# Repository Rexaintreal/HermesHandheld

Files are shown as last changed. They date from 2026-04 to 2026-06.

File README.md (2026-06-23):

# HermesHandheld

A portable handheld retro gaming console built from scratch using a Raspberry Pi Zero 2W with a 5" display, physical controls, battery management, and audio output. Designed to run NDS and other retro emulators.

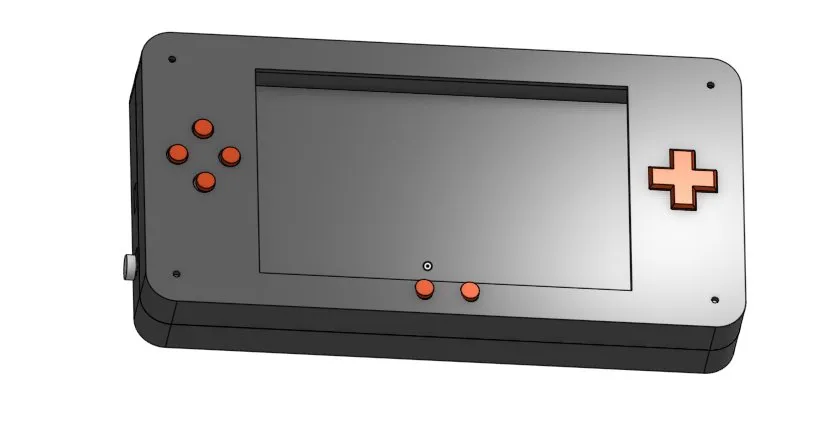
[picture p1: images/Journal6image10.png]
Assembly


> [!NOTE]
> **Currently on a short break!** I'm busy at the moment but will be actively continuing development soon. Stay tuned for updates!

---

## What is it?

Hermes is a fully custom handheld gaming console 3D printed case, hand-wired controls, and a Pi Zero 2W running emulators. Everything from the schematic to the CAD was designed from scratch.

---

## Why I built this

So while looking for inpirations for a Forge project i stubmled across the [simplyRetroZ5](https://www.printables.com/model/163507-simplyretro-z5-retropie-emulation-handheld) repository and i was really amazed by this project and i decided to build smthing like this myself but it would be challenging as ive never made anything from scratch before (in hardware). I had never made a schematic, never done CAD and had no experience with hardware design. But i wanted a project which would help me actually learn all of that not just follow some tutorial online. So instead of cloning it i found parts myself, created the case wiring schematic all myself from scratch. Currently Hermes is under development and im actively working on it whenever im free! 

## Features

- Raspberry Pi Zero 2W (64-bit, capable of NDS emulation)
- Waveshare 5" HDMI display
- ABXY buttons + D-Pad + Start/Select
- LiPo battery (3000mAh) with Adafruit PowerBoost 1000C for stable 5V + charging
- 3.5mm wired audio jack
- Slide switch power on/off
- Fully 3D printed enclosure (195×100×15mm)
- MicroUSB charging port

---

## Repo Structure

```
HermesHandheld/
├── ASSEMBLY.md         # Assembly guide 
├── JOURNAL.md          # Build log with progress photos
├── bom/bom.md          # Full bill of materials
├── cad/                # STL files for 3D printing
├── schematics/         # KiCad schematic + PDF export
└── images/             # All journal and build images
```

---

## CAD

All parts designed in OnShape from scratch.

[View OnShape Assembly](https://cad.onshape.com/documents/3f5750065cdf21957d49744e/w/c6da2cc7c075b2bb5bd5add7/e/7ea9707faccdc6ff577339ba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)

Printable STLs are in the `/cad` folder:
- `top_shell_ds.stl`
- `bottom_shell_ds.stl`
- `abxy_button.stl` (print x6)
- `dpad.stl`
- `power_button.stl`

---

## Schematic

Designed in KiCad. Uses Pi Zero 2W internal pull-ups for buttons (no external resistors needed).



[View Full Schematic PDF](schematics/HermesHandheld.pdf)
---

## Bill of Materials

[View BOM](bom/bom.md)

| Part | Details |
|---|---|
| Raspberry Pi Zero 2W | Main compute |
| Waveshare 5 Display | 121×76mm HDMI |
| Adafruit PowerBoost 1000C | LiPo charging + 5V boost |
| LiPo Battery 3000mAh | 3.7V, 60×50mm |
| Tactile buttons (x10) | 6×6×5mm |
| 3.5mm audio jack | Wired audio via GPIO18 |
| Slide switch | Power on/off |

---

## Build Journal

Full build log with progress photos: [JOURNAL.md](JOURNAL.md)

---

## Status

> CAD complete, schematic done, need to buy parts

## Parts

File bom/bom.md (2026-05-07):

# Bill of Materials 

| Item | Description | Quantity | Unit Price ($) | Total Price ($) | URL |
|---|---|---|---|---|-----|
| Raspberry Pi Zero 2 W | Main compute board (quad-core ARM CPU) | 1 | 20 | 20 | https://robu.in/product/raspberry-pi-zero-2-w/ |
| MicroSD Card 32GB (A1/A2) | OS + emulator + ROM storage | 1 | 6 | 6 | https://sharvielectronics.com/product/sandisk-32gb-class-10-ultra-microsd-uhs-u1a1-card-98mbps/ |
| 5" HDMI IPS Display (800×480) | Non-touch HDMI display for handheld | 1 | 30 | 30 | https://robu.in/product/waveshare-5inch-display-for-raspberry-pi-800x480-dpi-interface-ips-no-touch/ |
| HDMI To Mini HDMI Cable | HDMI connection for Pi/display setup | 1 | 2 | 2 | https://sharvielectronics.com/product/hdmi-to-mini-hdmi-cable-1-5-meter/ |
| LiPo Battery 3.7V 3000mAh | Main power source | 1 | 4.5 | 4.5 | https://www.electronicscomp.com/3.7v-3000mah-lipo-battery-india |
| Adafruit PowerBoost 1000C | Battery charging + 5V boost regulator | 1 | 30 | 30 | https://www.theengineerstore.in/products/adafruit-2465-powerboost-1000-charger-adafruit-rechargeable-5v-lipo-usb-boost-1a-1000c |
| SPDT Slide Switch | Power on/off control | 1 | 0.07 | 0.07 | https://sharvielectronics.com/product/ss12f44-3pin-spdt-slide-switch-with-single-row-vertical-pcb-mountable-3mm-pitch/ |
| Tactile Push Buttons (6x6mm) | ABXY + Start/Select inputs | 12 | 0.04 | 0.48 | https://sharvielectronics.com/product/6x6x5mm-tactile-push-button-switch-black-dip-package/ |
| 3.5mm Audio Jack Module | Wired headphone audio output | 1 | 0.01 | 0.01 | https://robu.in/product/smartelex-audio-jack-3-5mm-trrs-smd/ |
| Jumper Wires (40 each) | Internal wiring | 1 pack | 0.9 | 0.9 | https://sharvielectronics.com/product/male-to-male-jumper-wire-connector-40-pieces/ |
| 2×20 40Pin Male Berg Strip Header | GPIO header for Pi Zero 2W | 1 | 0.15 | 0.15 | https://sharvielectronics.com/product/2x20-40pin-male-double-row-straight-berg-strip-connector-11mm-height-2-54mm-pitch/ |
| Resistor Kit | Pull-ups for button circuits | 1 | 2 | 2 | https://robu.in/product/30-different-valued-metal-film-resistor-assorted-kit-for-diy-electronic-projects-and-experiments/ |
| Breadboard | Wiring and prototyping | 1 | 0.7 | 0.7 | https://sharvielectronics.com/product/gl-12-830-points-solderless-breadboard/ |
| M2 Screw + Standoff Kit | Assembly for 3D printed case | 1 | 1 | 1 | To be decided while assembly (after 3d case design) |
| 3D Printed Case (PLA) | Custom enclosure for Hermes | 1 | 30 | 30 | To be decided after building the full project |
| | | | **Total** | **$127.81** | |

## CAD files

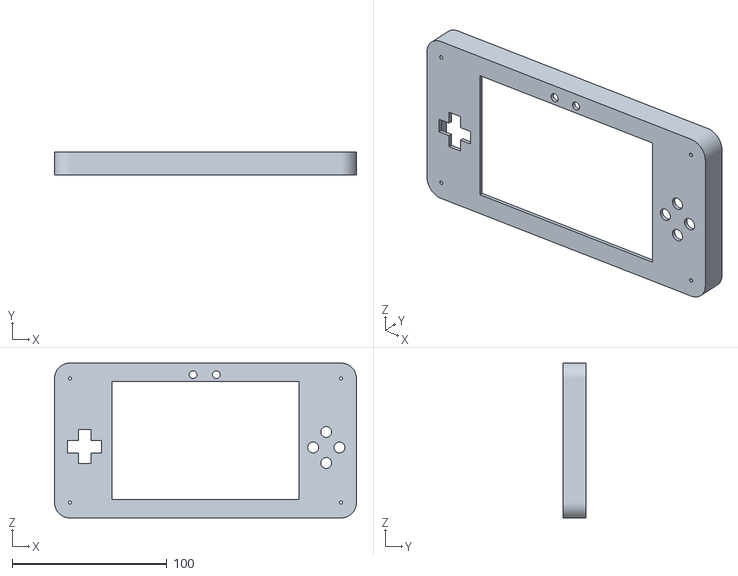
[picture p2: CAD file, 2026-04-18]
cad/top_shell_ds.stl
195.0 x 15.0 x 100.0

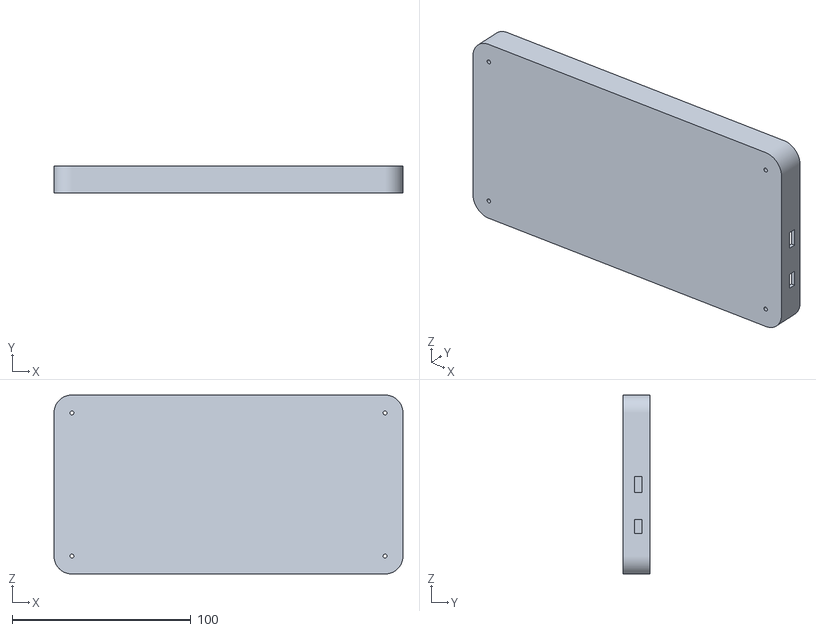
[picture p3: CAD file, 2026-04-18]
cad/bottom_shell_ds.stl
195.0 x 15.0 x 100.0

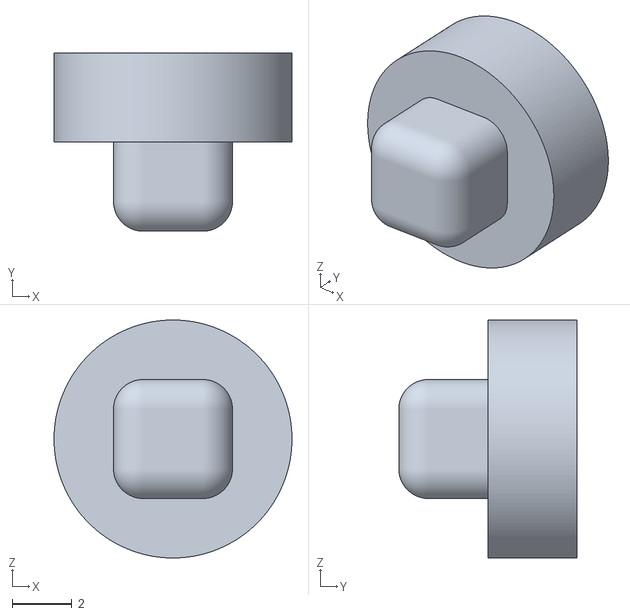
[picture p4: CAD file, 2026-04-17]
cad/power_button.stl
8.00 x 6.00 x 8.00

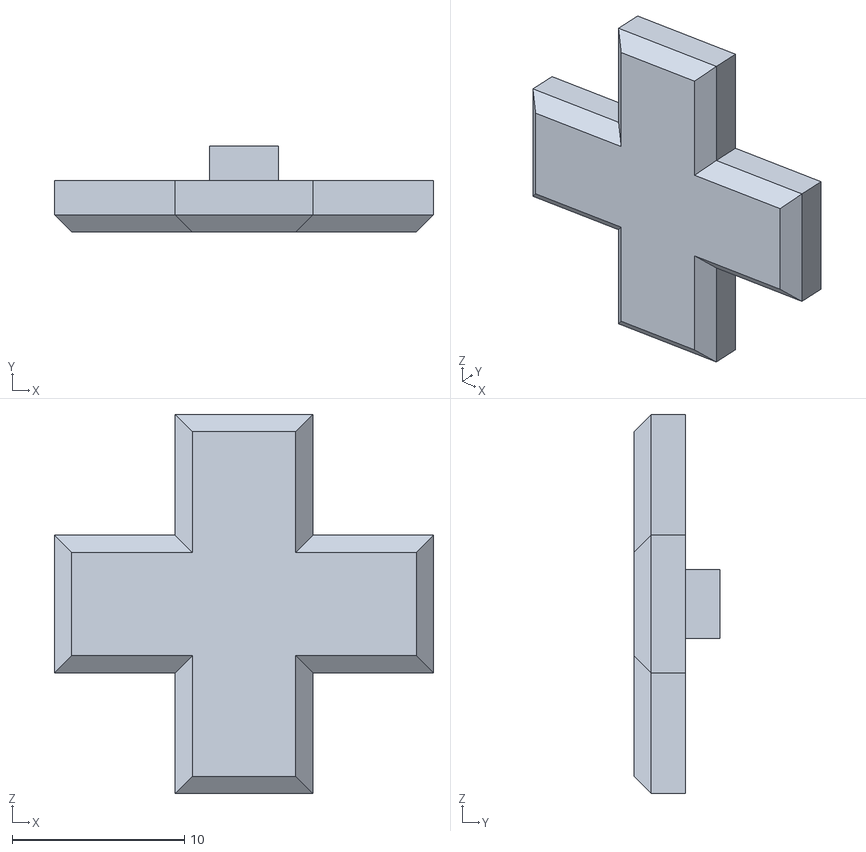
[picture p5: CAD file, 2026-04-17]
cad/dpad.stl
22.0 x 5.00 x 22.0

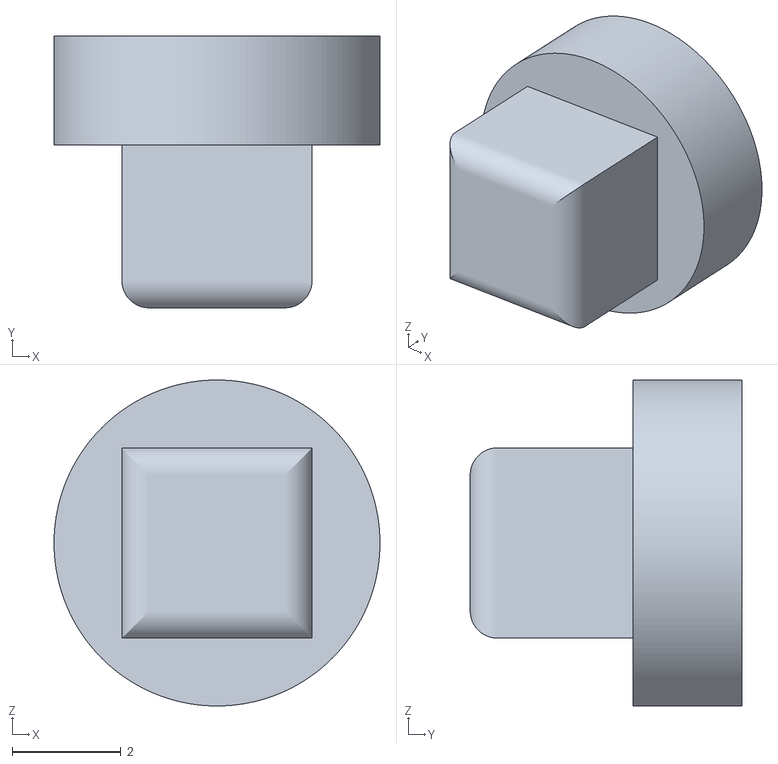
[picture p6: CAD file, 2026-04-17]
cad/abxy_button.stl
6.00 x 5.00 x 6.00

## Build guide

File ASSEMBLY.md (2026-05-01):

# Assembly

A detailed guide to assemble the hermes handheld gaming console from 3d Printed parts, handwiring and other components.

---

## Before You Start

### Tools Required
- Soldering iron + solder
- Wire strippers
- Small screwdriver (M2)
- Hot glue gun or Superglue
- Multimeter (recommended for checking connections optional tho)
- Helping hands / PCB holder (optional but useful for soldering)

### Parts Required
Refer to [bom/bom.md](bom/bom.md) for the full bill of materials. in brief you will need these:

| Part | Qty |
|---|---|
| Raspberry Pi Zero 2W | 1 |
| Waveshare 5" HDMI Display | 1 |
| Adafruit PowerBoost 1000C | 1 |
| LiPo Battery 3000mAh (3.7V, 60×50mm) | 1 |
| Tactile switches (6×6×5mm) | 10 |
| 3.5mm audio jack | 1 |
| Slide switch (SPDT) | 1 |
| Jumper wires | several |
| M2 screws | 4 |

### 3D Printed Parts Required
Print all STLs from the `/cad` folder before starting. Recommended settings: 0.2mm layer height, 20% infill, PLA.

| File | Qty |
|---|---|
| `bottom_shell_ds.stl` | 1 |
| `top_shell_ds.stl` | 1 |
| `abxy_button.stl` | 6 |
| `dpad.stl` | 1 |
| `power_button.stl` | 1 |

---

## Soldering Headers onto the Pi Zero 2W

if the pi zero 2w ships without headers we need to add the header pins to it 
1. Place the 40-pin male header into the Pi Zero 2W GPIO holes.
2. Solder each pin carefully making sure there are no bridges between adjacent pins.
3. Let it cool completely and properly
---

## Preparing the PowerBoost 1000C

1. Solder short jumper wires to the following PowerBoost pads:
   - **BAT+** and **BAT−** to for the LiPo battery
   - **5V** and **GND** to for powering the Pi Zero 2W
   - **EN** to the slide switch (used for power on/off)
2. Solder two wires to the slide switch and connect one end to the **EN** pad on the PowerBoost and the other to **GND** when the switch breaks the EN–GND connection the PowerBoost will turn off

---

## Wiring the Battery

1. Connect the LiPo battery's JST connector to the **BAT** port on the PowerBoost 1000C.
   - If no JST connector solder the red wire to **BAT+** and black wire to **BAT−**.
2. Double check the polarity with a multimeter before connecting or it might damage components

---

## Connecting the Pi Zero 2W to the PowerBoost

1. Solder or use jumper wires to connect:
   - PowerBoost **5V** to Pi Zero 2W **Pin 2 (5V)**
   - PowerBoost **GND** to Pi Zero 2W **Pin 6 (GND)**
2. now we can do a quick power test: flip the slide switch and verify the Pi boots (green LED on Pi should blink :3)

---

## Connecting the Display

1. Connect the Waveshare 5" display to the Pi Zero 2W using the Mini HDMI cable/adapter.
2. The display also needs power  connect its **5V** and **GND** pins to the Pi's **5V** and **GND** pins (or tap off the PowerBoost output).
3. Refer to the schematic PDF in `/schematics` for exact pin labeling.

---

## Wire the Buttons

All 10 tactile switches use the Pi Zero 2W's internal pull-ups  no external resistors are needed.
Wire each button between its GPIO pin and **GND** (Pin 14 or any GND pin). The Pi will read LOW when a button is pressed.

| Button | GPIO Pin |
|---|---|
| A | GPIO 17 |
| B | GPIO 27 |
| X | GPIO 22 |
| Y | GPIO 10 |
| Start | GPIO 9 |
| Select | GPIO 11 |
| D-Pad Up | GPIO 5 |
| D-Pad Down | GPIO 6 |
| D-Pad Left | GPIO 13 |
| D-Pad Right | GPIO 19 |

> These pin assignments are based on the KiCad schematic Confirm against `/schematics` before soldering.

1. Solder one leg of each tactile switch to its GPIO wire and the other leg to a shared GND wire
2. Keep wires as short as practical so everything fits inside the shell

---

## Wiring the Audio Jack

1. Connect the 3.5mm audio jack to **GPIO 18** on the Pi Zero 2W (PWM audio output).
2. Also connect the jack's ground sleeve to Pi **GND**.
3. PWM audio requires a simple RC filter for acceptable quality a 270 ohm resistor in series and a 33nF capacitor to ground on each channel is recommended, though optional for basic testing.

---

## Seat Components into the Bottom Shell

The bottom shell (195×100×15mm) houses all the internals.

1. Place the **LiPo battery** flat in the center/lower area of the bottom shell.
2. Place the **PowerBoost 1000C** in the upper-left corner near the MicroUSB charging cutout.
3. Place the **Pi Zero 2W** in the remaining space, with the GPIO pins facing inward.
4. Slide the **slide switch** into the 8×4mm cutout on the side wall.
5. Fit the **MicroUSB port** of the PowerBoost through the 9×4.5mm cutout on the side wall.
6. Use hot glue sparingly to tack components in place if needed.

> Make sure no wires are pinched against the walls before closing the shell.

---

## Seat the Buttons into the Top Shell

1. Drop each **ABXY button** into its corresponding hole on the right side of the top shell.
2. Place the **D-Pad** into the left-side cutout.
3. Insert **Start** and **Select** buttons into the bottom center cutouts.
4. Press the **power button** into the side cutout.
5. The tactile switches sit underneath each button cap make sure they are aligned so pressing each cap actuates the switch directly below.

---

## Mounting the Display

1. Slide the **Waveshare 5" display** into the screen cutout on the top shell from the inside.
2. The display should sit flush with the front face of the shell.
3. Use hot glue to keep it in place if loose but it should be perfectly fit as the measurments are accurate

---

## Closing the Shell

1. Carefully fold all wires into the bottom shell so nothing comes out
2. Insert an M2 nut into the top shell hole from the inside before closing
3. Push an M2 screw up through the bottom shell from the outside
4. The screw threads into the nut inside the top shell, clamping them together
5. The nut might need a tiny dab of hot glue to stop it spinning while you screw in

---

## Power On and Test

1. Flip the slide switch to power on.
2. Verify:
   - [ ] Display turns on and shows Pi boot screen
   - [ ] All 10 buttons register input (test with a simple GPIO script)
   - [ ] Audio jack produces sound
   - [ ] MicroUSB charges the battery (PowerBoost LED should indicate charging)
3. If anything does not work, open the shell and re-check the relevant wiring against the schematic in `/schematics`.

---

Once assembled, flash your MicroSD card with your OS of choice (RetroPie, Batocera, or Raspberry Pi OS i aint planning for a custom firmware right now) and configure button mappings in your emulator frontend.

Refer to [JOURNAL.md](JOURNAL.md) for the full build log

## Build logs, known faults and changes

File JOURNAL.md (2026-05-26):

---
title: "HermesHandheld"
author: "Saurabh Tiwari"
description: "A custom handheld pi zero retro console"
created_at: "2026-04-14"
---

# April 14: Finding Parts and making BOM

So i found this supercool project while looking for inspiration on printables [simplyRetroZ5](https://www.printables.com/model/163507-simplyretro-z5-retropie-emulation-handheld) it was too advanced for me tho it has speakers, custom firmware etc which i am not planning to add in my hermes handheld project but this gave me a rough picture on what things i will need to build this project.



Core 
---------------
for Hermes i will use decided to use pi zero 2w instead of pi zero as it is more capable and finding pi zero can't handle nds emulation as it is too underpowered the zero 2w also supports 64bit architechture 

Display 
---------------
For the display any 5 inch display would work we don't need touch etc so i decided to go with the waveshare 5 inch display

ZY18318926_4

Battery
---------------
We need atleast 2000 mah and 3.7v battery so we could get a few hours of backup but along with this we would need a powerboost so it could give a stable 5V and handles charging via usb-c The Adafruit PowerBoost 1000C fits perfectly here since it:
- Boosts battery voltage to stable 5V  
- Handles LiPo charging  
- Provides safe power regulation for portable builds

for the battery we can go with any battery which meets the voltage and capacity requriements also for the power on off we would need a slide switch
81vWDk1H7JL _SL1200_

Audio
---------------
Currently our goal is only wired 3.5 mm jack to make things simple we could add 1W small speakers maybe later idk so a 3.5 mm audio jack would work 

Control
---------------
for controls we will go with the tactical buttons and maybe a dpad for hard plastic 
- ABXY
- Start / Select
- D-pad (likely a 4-button layout or hard plastic cap design)

Misc
---------------
Other supporting components include:
- MicroSD card slot and storage setup  
- Resistors for pull-ups and button stability  
- Jumper wires and headers for internal wiring  
- Breadboard for initial testing  
- Possible custom PCB later if everything works well  
- Fully 3D printed case for final enclosure  

With all this in mind i created the [BOM.md](https://github.com/Rexaintreal/HermesHandheld/blob/main/bom/bom.md) 

**Total time spent: 1 hour**

# April 15: Creating the Schematic in KiCad
---------------
I have never made a schematic before so this was a really new experience for me I used KiCad since it was free and everyone seems to use it.

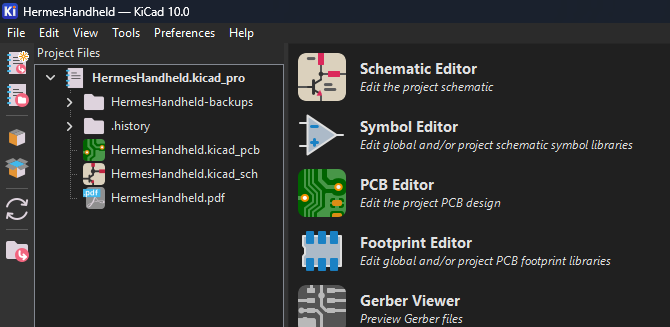
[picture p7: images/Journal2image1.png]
KiCad


---------------

I Started with the power section first i added a Conn_01x02 as the battery block then a SW_SPDT for the slide switch then a Conn_01x04 for the Power Boost 10000C and i used Labeling instead of drawing wires to keep everything clean.
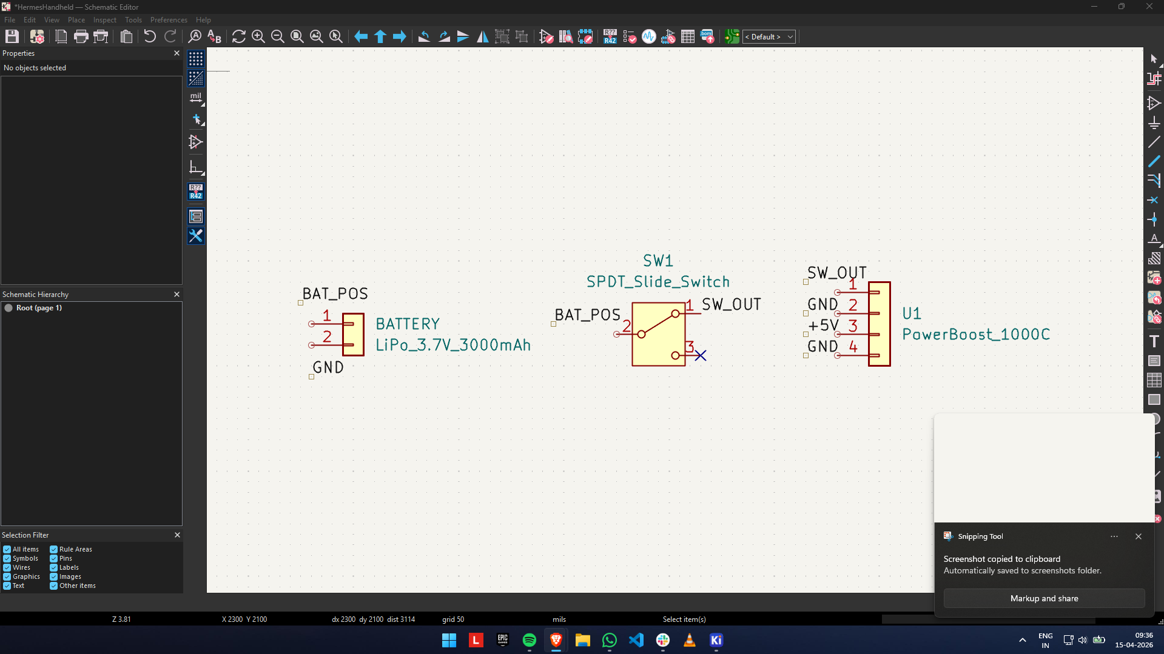
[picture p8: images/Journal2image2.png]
PowerSection


---------------
Then i added the pi zero 2w as a conn_02x20 40 pin block and labled only the pins i actually need 5V GND and the 10 pins for the buttons then i marked everything else as no connect with X marks.
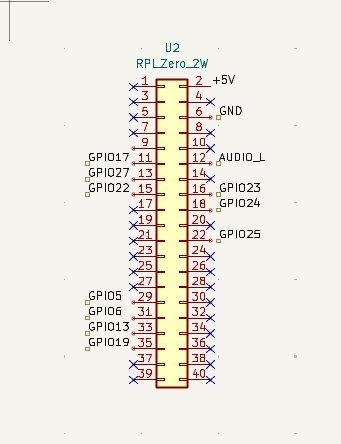
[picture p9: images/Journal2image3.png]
PiZero


---------------
After this i added all 10 buttons ABXY, Start, Select, D-Pad as SW_Push symbols. originally i was going to add external 10k pull up resistors for each button but turns out the pi zero has internal pull ups which we can enable in the software for simpler schmatic.
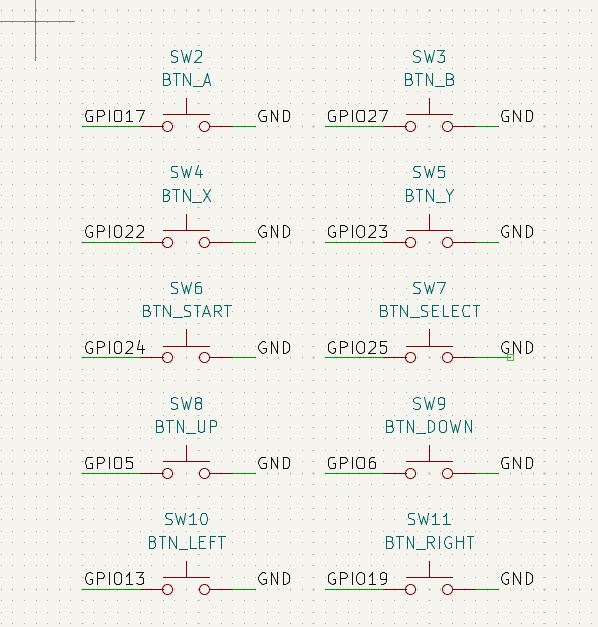
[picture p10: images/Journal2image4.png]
Buttons


---------------

Now i added a 3.5mm audio jack 3 for the wired audio connected to gpio18 (pwn audio) and a conn_01x05 for the waveshare display with HDMI_P and HDMI_N labels. I got some warning about HDMI_P and HDMI_N only connecting to one pin each but thats expected as hdmi is a physical cable. i added a note for it 
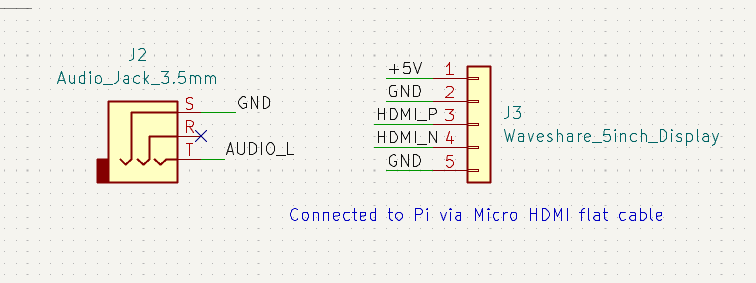
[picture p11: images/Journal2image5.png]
AudioDisp


---------------

I ran into some ERC errors fixed the no connection on pins and there were some misclicks too the final result had 0 errors with 2 harmless warnings about the hdmi.
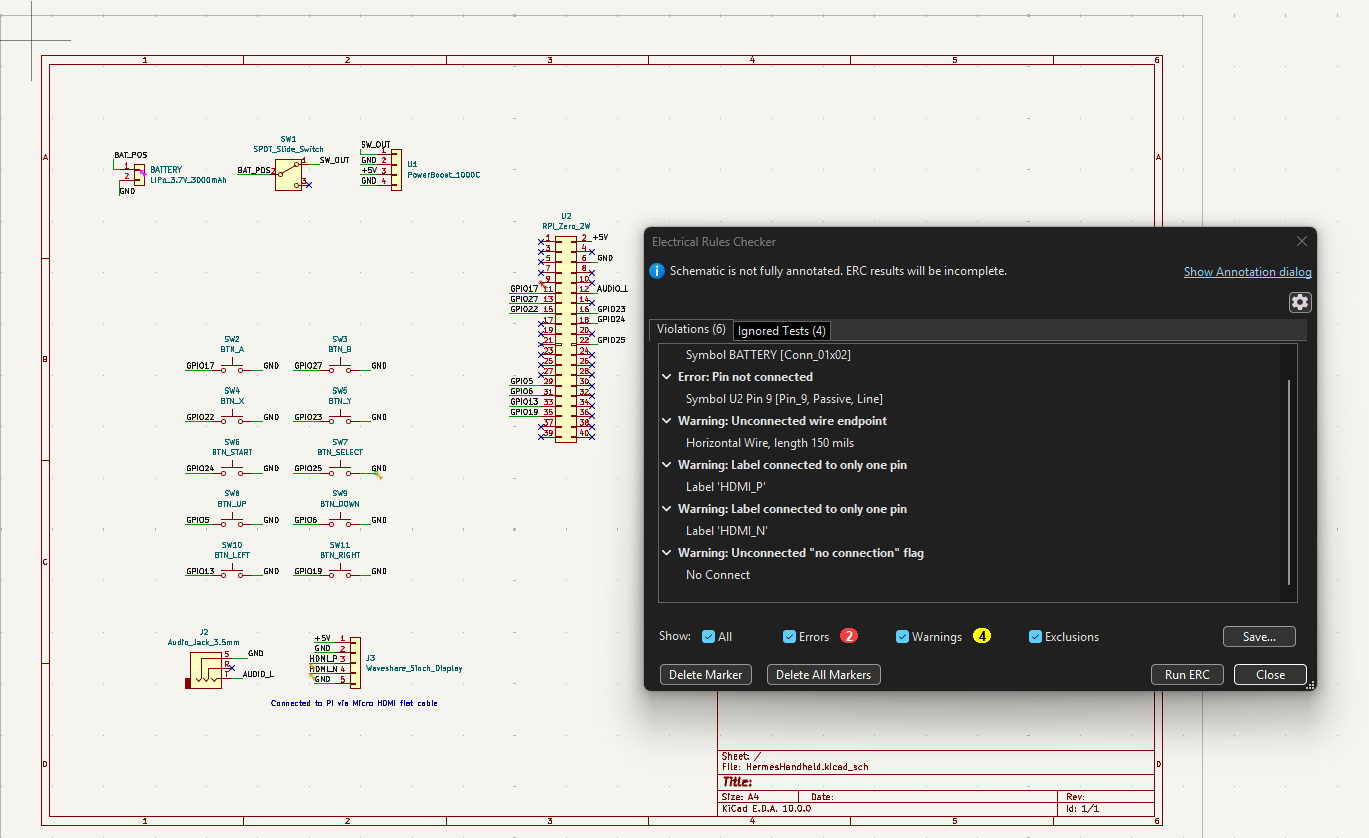
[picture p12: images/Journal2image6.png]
Errors


---------------

The final schematics can be seen in the Github folder at [PDFLink](https://github.com/Rexaintreal/HermesHandheld/blob/main/schematics/HermesHandheld.pdf)

**Total time spent: 1.5 hours**

# April 16: Designing the bottom shell in onshape

Ive never done any CAD before so this was a very intimidating task for me i decided to use onshape its free and runs on the browser (also i found some tutorials too).

---------------
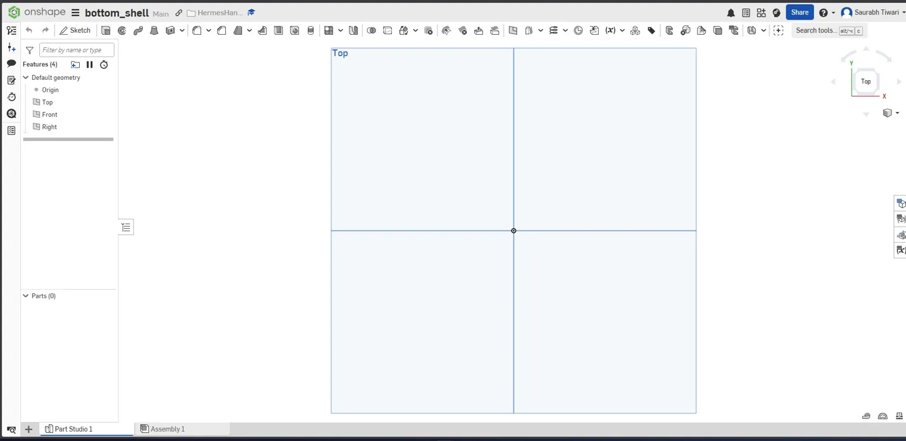
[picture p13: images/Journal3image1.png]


---------------

Before starting i looked up the exact dimensions fo every part from my BOM.md from datasheets so i make the models correctly
- Pi Zero 2W: 65×30×5mm
- Waveshare 5" Display: 121×76×5mm  
- PowerBoost 1000C: 32×19×5mm
- LiPo 3000mAh: 60×50×8mm
- Tactile buttons: 6×6×5mm each

Based on the biggest parts (bettery + pi) i decided to make the bottom shell to be 160mm wide 80mm tall and 15mm deep with 2mm thick cornered walls

---------------

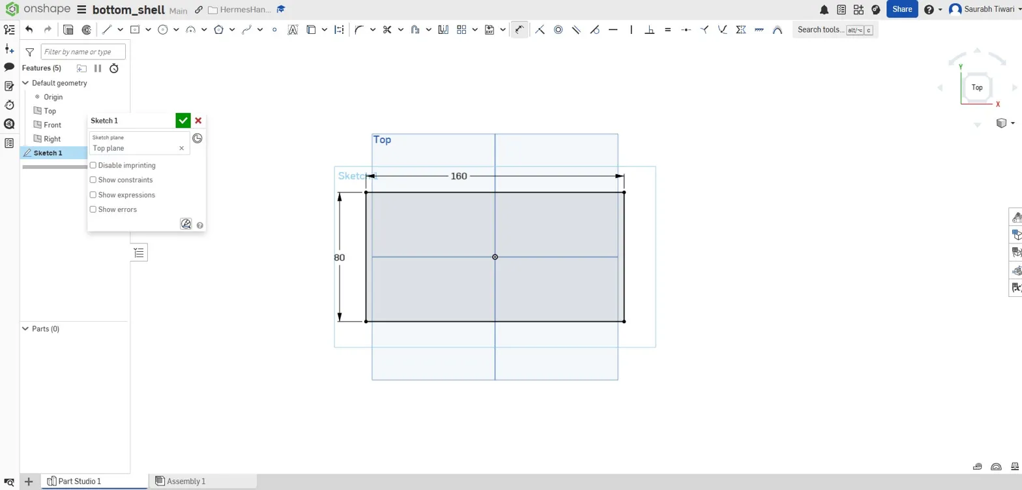
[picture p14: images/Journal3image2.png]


---------------

I started with a sktech o nthe top plane and drew a 160x80mm rectangle and then added a 10mm fillets on all 4 corners (i will regret that - foreshadowing) so it looks like an actual handheld and not a BRICK then used the offset tool at -2mm to create the inner wall boundary

---------------

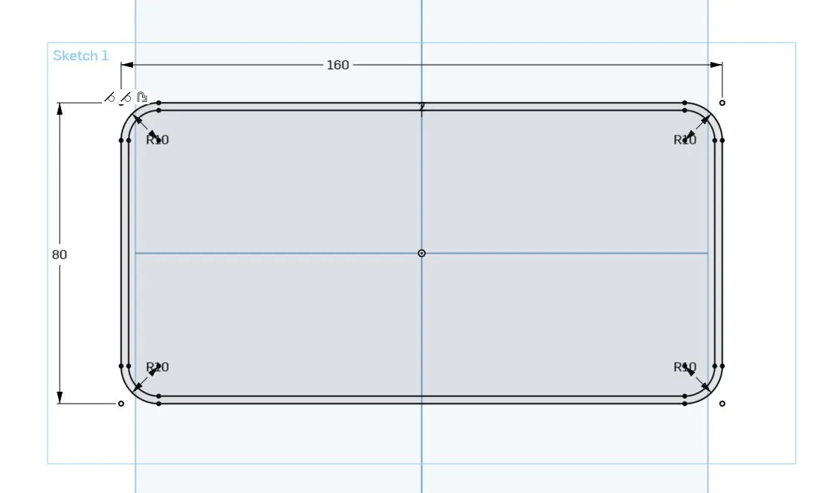
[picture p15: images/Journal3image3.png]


---------------

Extruded the wall profile to 15mm to get the tray shape.

---------------
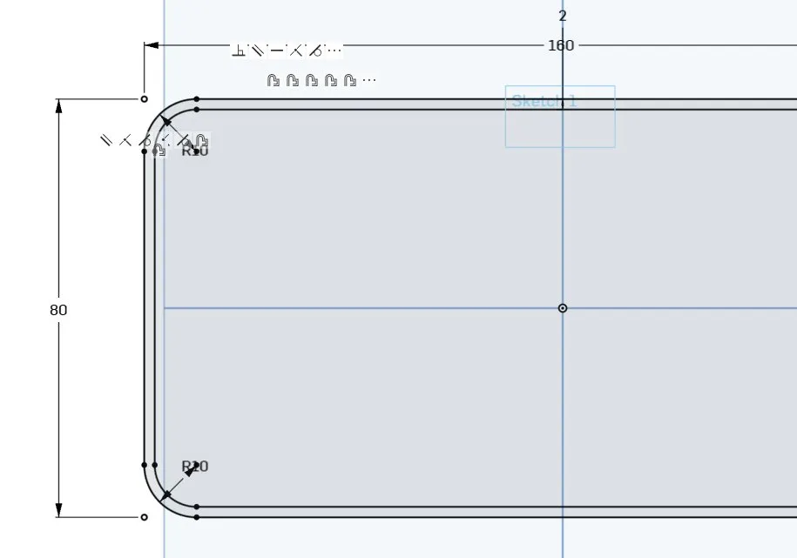
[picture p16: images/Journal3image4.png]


---------------
then i made the floor/base of the case 

---------------
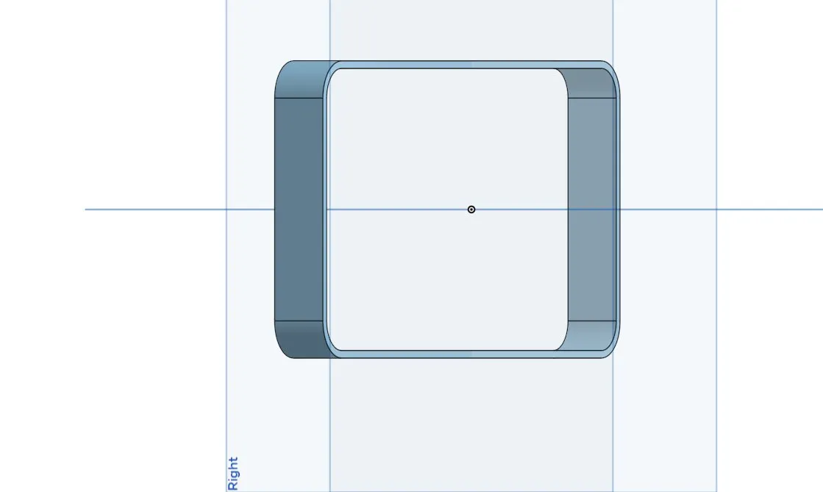
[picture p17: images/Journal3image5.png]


---------------

Now i had to add 4 m2 screws holes in all the four corners (2.2mm dia for clearance) and 5mm from the edges. these go all the way through so the screws can be inserted from the back to hold the top and bottom shell together. 

---------------
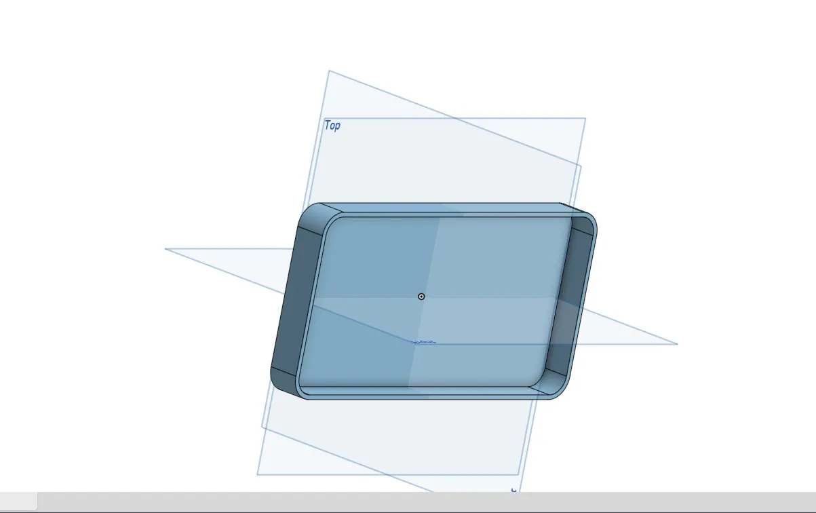
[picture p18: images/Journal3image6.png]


---------------

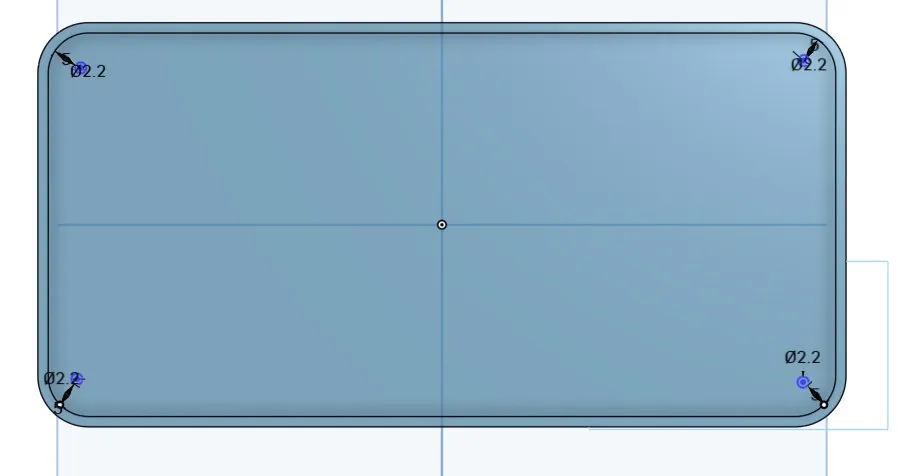
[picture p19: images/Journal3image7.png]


---------------

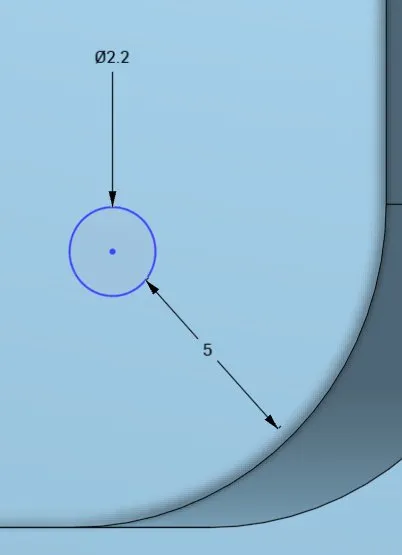
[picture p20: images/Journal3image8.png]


---------------

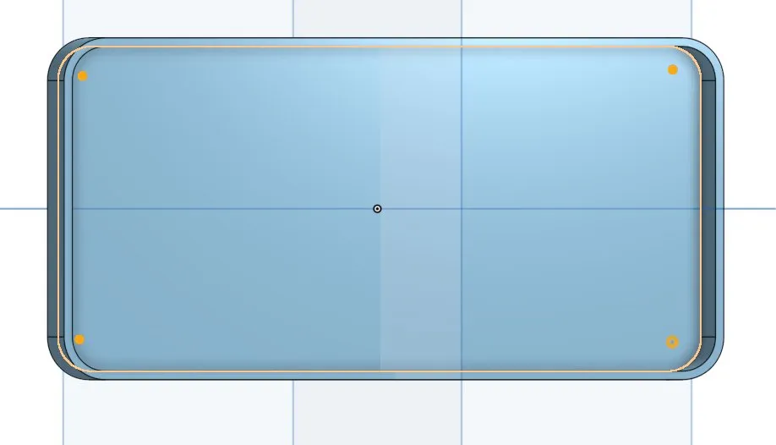
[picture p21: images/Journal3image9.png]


---------------

I struggled with the alginment alot the contrains of being 5mm form the fillet corner works and the dia is also 2.2mm but the placment was inconsistent on all the 4 corners i tried fixing it but i couldnt find any solution and that how i end today's forging session.

---------------

**Total time spent: 1.5 hours**

# April 17: Power Button, Bottom Shell Cuttouts, ABXY buttons and DPad

So i Fixed the screw hole thanks to Anicetus on slack i used the cocentric constraint to make it all aligned 

---------------

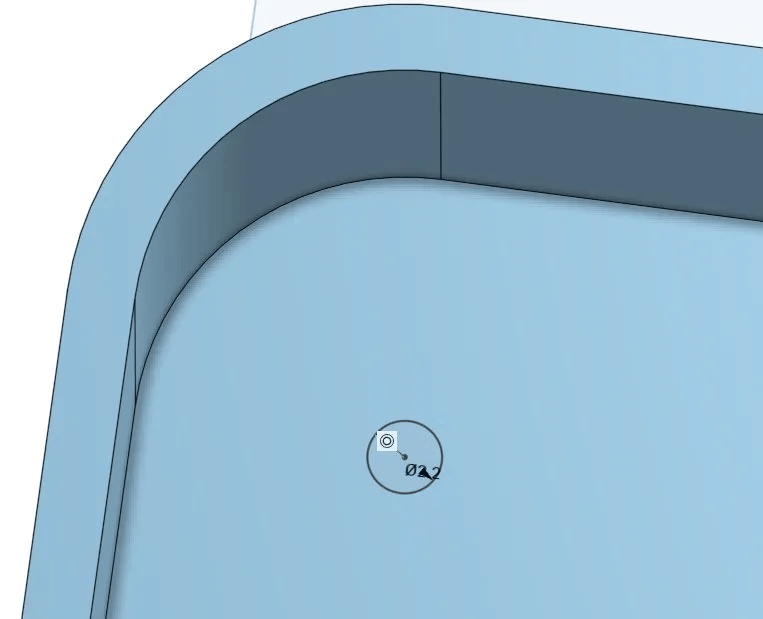
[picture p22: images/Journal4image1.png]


---------------
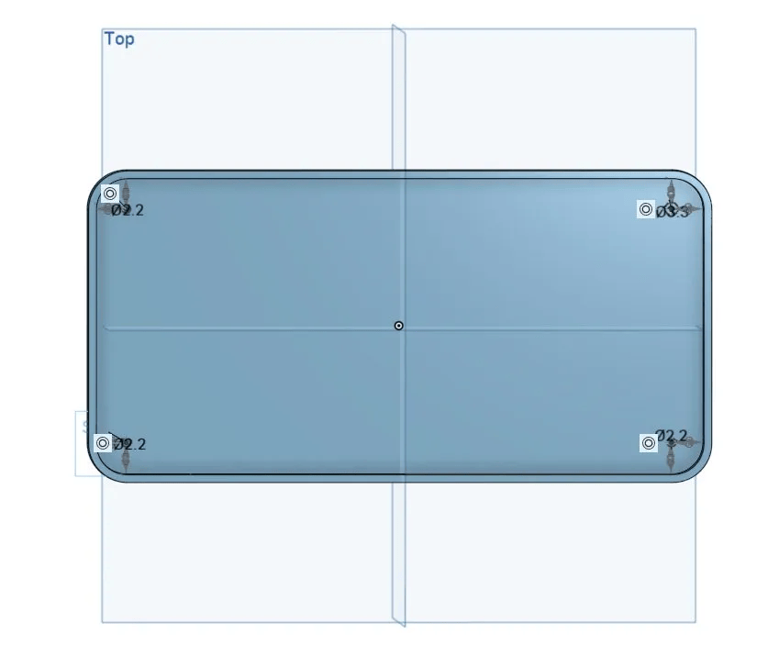
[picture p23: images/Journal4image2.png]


---------------

After that i added two cutouts on the side wall of the bottom shell
- One for the Micro Usb slot for charging 9x4.5mm from bottom for powerboost charging module
- and second for the slide switch 8x4mm and 15mm from usb slot so it is placed a bit further

---------------
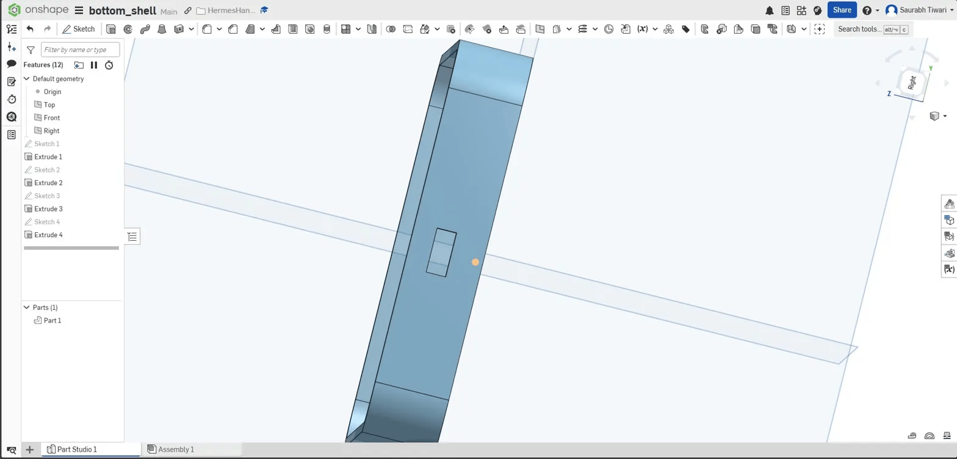
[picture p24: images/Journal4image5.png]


---------------
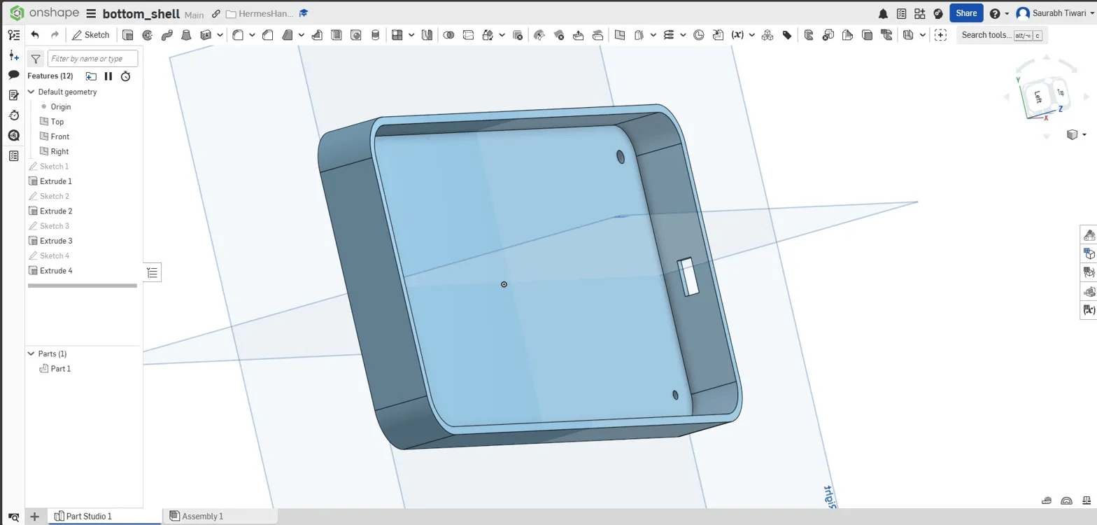
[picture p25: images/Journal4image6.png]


---------------
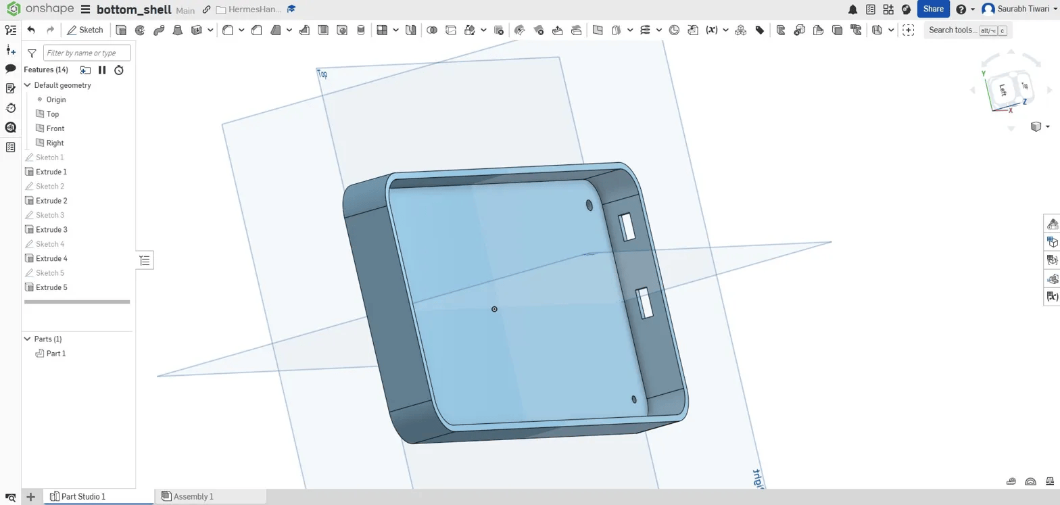
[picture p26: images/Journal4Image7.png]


---------------

After this the bottom shell was finally complete!! then i started workikng on the smaller parts like the buttons etc
I started wit the power button first a small circle then a stem then i rounded it a bit.

---------------
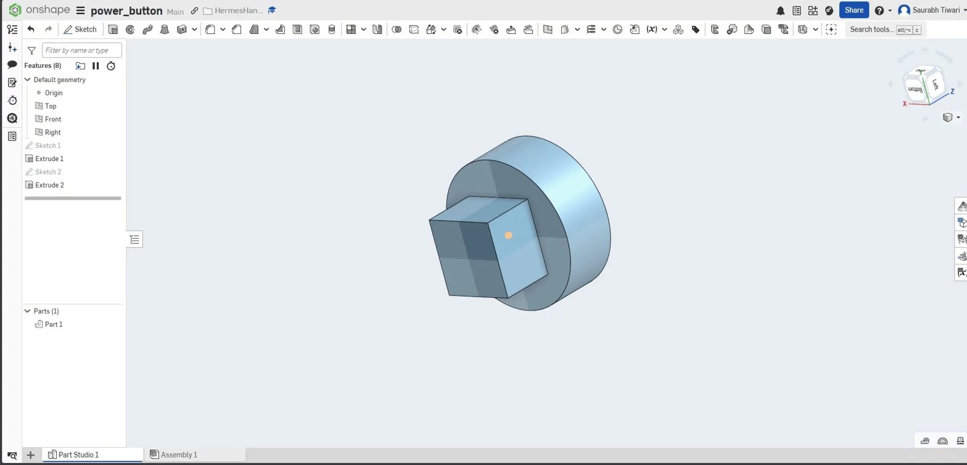
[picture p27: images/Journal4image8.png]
Power Button


---------------

Similarly i started the ABXY button it is one button design but weve to print 4 of it for each action A B X and Y i didnt engrave text on it as it would be difficult to print properly.

---------------

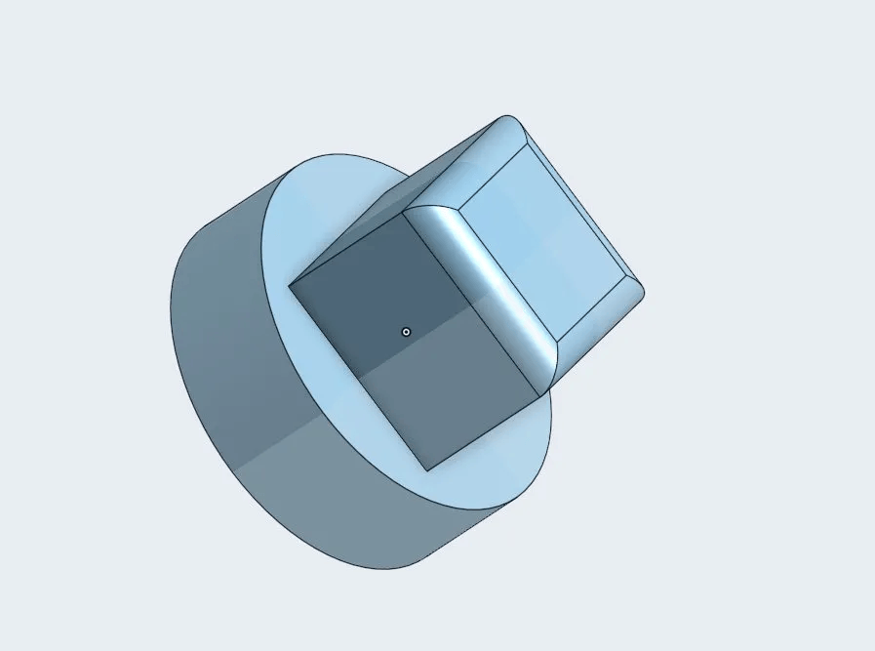
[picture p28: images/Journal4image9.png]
ABXY


---------------

Now it was time for the DPad I wanted a GBA styled dpad with individual 6x6x5mm tactical switch beneath it so i started with two rectangles sketch and added a pivot at the bottom so it would work properly for movements in any direction

---------------

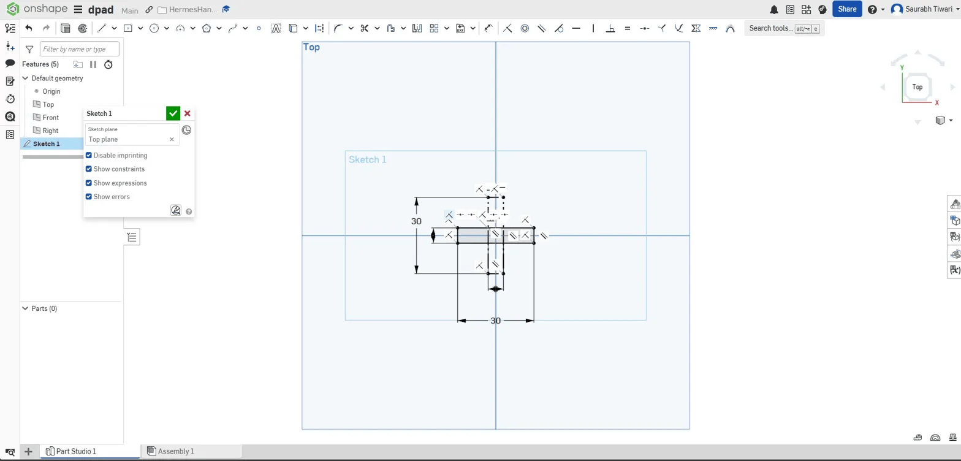
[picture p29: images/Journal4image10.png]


---------------
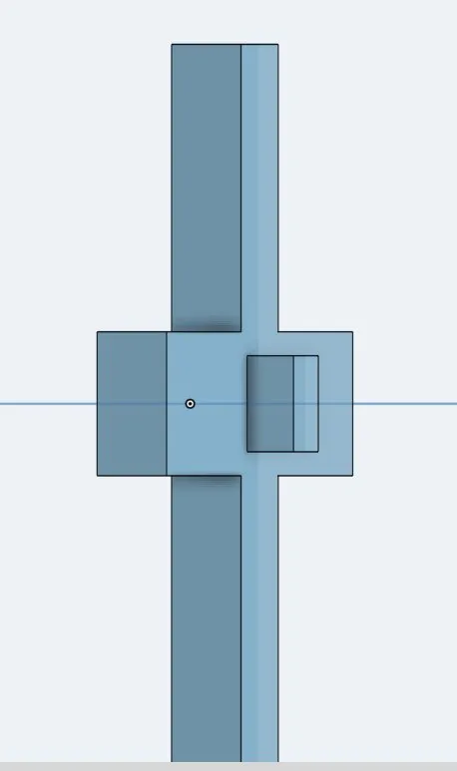
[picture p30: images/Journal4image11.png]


---------------

But it was not looking like a dpad something was off so i tried making the rectangles X cross to be of similar size like a square i changed the dimensions from 30 to 22 and from 12 to 8mm

---------------
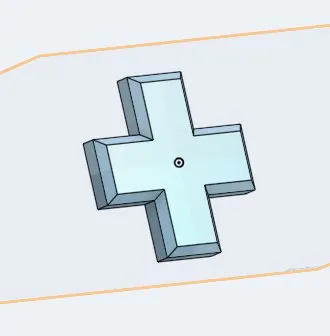
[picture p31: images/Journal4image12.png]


---------------

Finally before ending todays cad session i tried making the top shell just the hollow shell with same dimensions as the bottom shell with fillet used on the corners for consistency. it is unfinished atm.
---------------
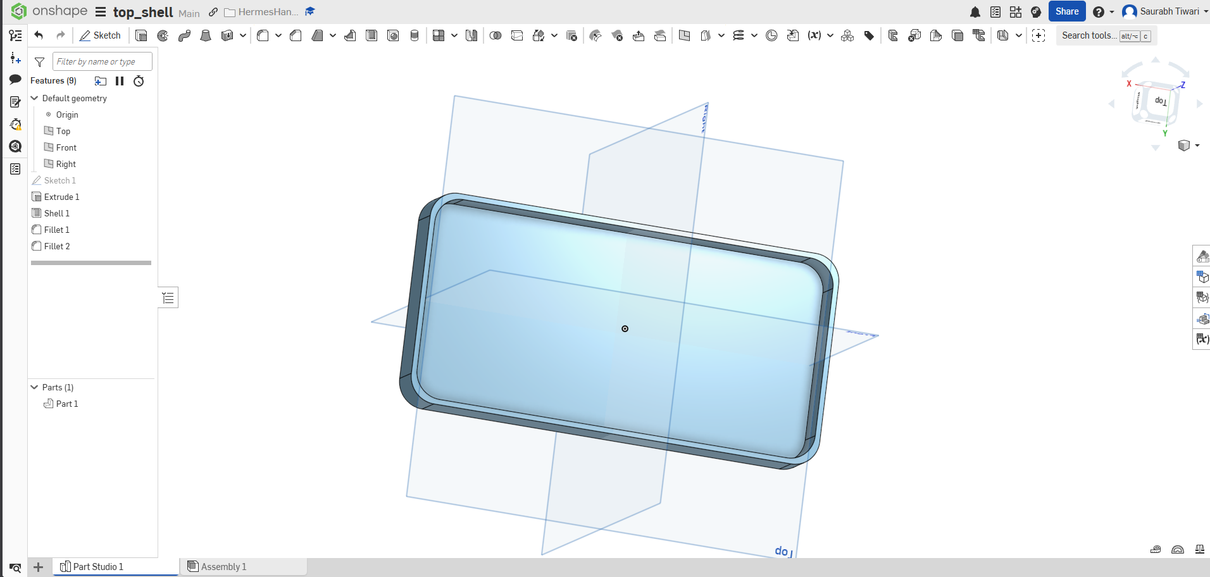
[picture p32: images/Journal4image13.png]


---------------

**Total time spent: 2 hours**

# April 18: Designing the DS Style Top Shell and Redesigning the Bottom Shell

So i continued with the top shell and i was adding the hole for the dislay mount and i realized the dimensions of the display are way larger and this leaves no space for the controls like i imagined.

---------------
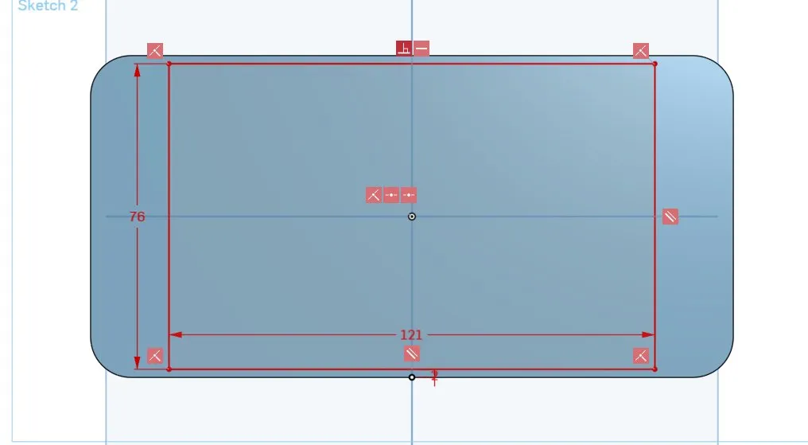
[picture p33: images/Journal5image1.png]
Error


---------------

after reconsidering all the dimensions i started redesigning the shells as they were not fit for the dispaly and controls 

---------------
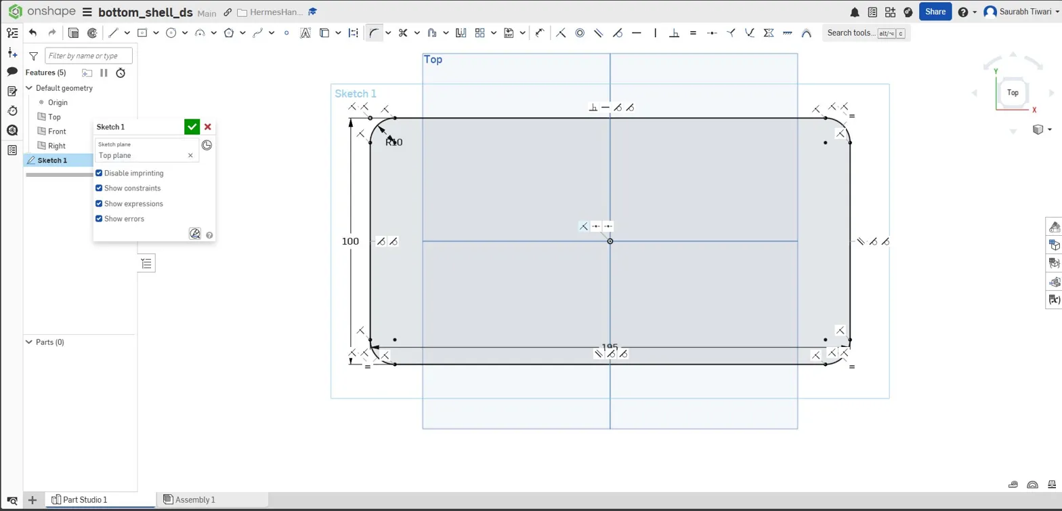
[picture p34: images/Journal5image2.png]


---------------

Based on the component sizes i recalculated everything:
- 35mm left (dpad zone) + 121mm (display) + 35mm right (abxy zone) = 191mm inner
- With 2mm walls each side = 195mm total width
- 10mm top gap + 76mm display + 10mm bottom (start/select) = 96mm inner  
- With 2mm walls = 100mm total height
- Depth stays 15mm
- and the bottom shell with new 195×100×15mm dimensions.

---------------
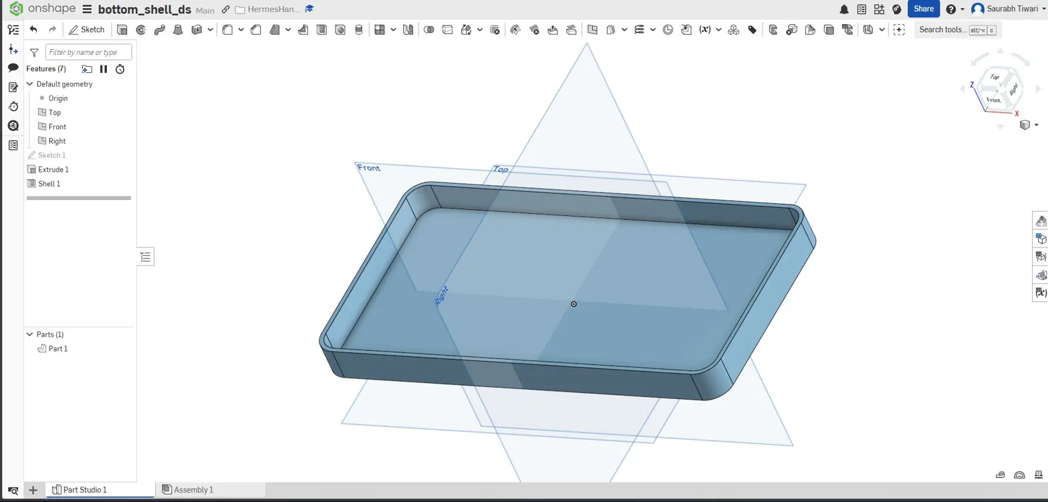
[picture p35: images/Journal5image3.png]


---------------
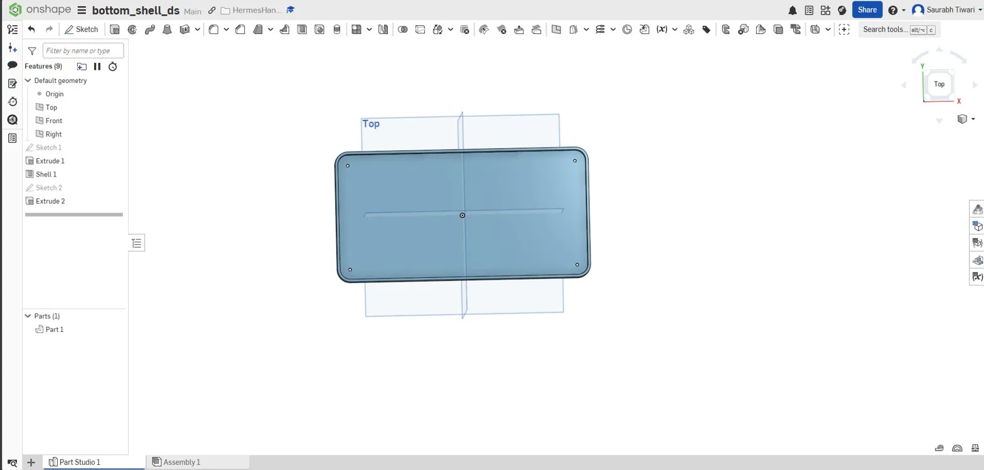
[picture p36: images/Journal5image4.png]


---------------

After completing the bottom shell i added the cuttouts for the usb and slide switch 

---------------
BottomShelRedesigned

---------------

then i continued with the top shell by creating the similar shell like strucutre and then excruding out space for the screen.

---------------
TopShell

---------------

TopShell

---------------

Now it was time for the buttons ABXY i wanted them to be on the right hand side in center but the distance were inconsistent

---------------

TopShell

---------------

So i redrew it properly it took a while but it was looking like a real handheld now 

---------------

TopShell

---------------

similarly i drew the dpad and the select and start button and added screw holes and added the 3.5 mm audio jack hole in the end to finish the CAD!!!

i FINALLY CREATED THE CASE FROM SCRATCH YAYAYAYAYAYAY 

---------------

TopShell

---------------

TopShell

---------------

TopShell

---------------

TopShell

---------------

**Total time spent: 1.5 hours**

# April 24: Creating the Assembly and Coloring in OnShape

So today the reviewer asked me to create an assembled view of all the parts so they can verify everything fits together and also asked for the onshape links so i had to figure out how to use the Assembly feature in onshape which i had never used before.

---------------

I started by creating a new Assembly tab in my onshape document by clicking the + button at the bottom next to the Part Studio 1 tab At first the assembly was completely empty (Parts 0) so i had to figure out how to insert parts into it. I pressed I to open the insert menu and found all my parts listed there I started inserting the parts one by one the top shell and bottom shell went in first but they were all floating around in random positions it looked like a mess lol

---------------
Assembly

---------------

Parts

---------------

---------------
Assembly

---------------

then i started dragging everything into place putting the dpad on the left side of the top shell where it belongs

---------------
Assembly

---------------

after placing all the parts it was starting to look like an actual handheld!! the shells fit together nicely and there was room for all the buttons

---------------
Assembly

---------------

i checked the side profile too to make sure the power button and usb cutout were visible and aligned properly

---------------
Assembly

---------------

the start and select buttons on the bottom also looked correctly placed

---------------
Assembly

---------------

this is the clean assembled front view before adding any colors it was already looking really good and like a real handheld!!

---------------
Assembly

---------------

then i decided to add some colors to make it look more presentable for the reviewer. i right clicked on each part in the viewport and used Edit Appearance to change colors. started with making the shells dark gray

---------------
Assembly

---------------

then i colored the buttons i made the abxy buttons red and the dpad orange to make them stand out against the dark shell

---------------
Assembly

---------------

after some more tweaking with the colors i got to a final look that i was happy with gray shell with red abxy buttons orange dpad and the start select buttons also colored
this is the final assembled render!! it looks like a proper retro handheld and all the parts fit together as planned. you can clearly see the screen cutout dpad abxy buttons start select and the power button on the side

---------------

The final assembled onshape document can be viewed here: [OnShape Assembly Link](https://cad.onshape.com/documents/3f5750065cdf21957d49744e/w/c6da2cc7c075b2bb5bd5add7/e/7ea9707faccdc6ff577339ba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)

---------------
after finishing the assembly i also wrote a proper README.md for the github repo since the reviewer mentioned shipping and having good documentation. it covers what hermes is, the features, the repo structure, links to the onshape assembly, schematic pdf, and bom. so anyone landing on the repo understands what the project is about immediately.

**Total time spent: 1 hour**

# May 1: Writing Assembly Instructions

So the reviewer sent it back asking for assembly instructions and a motivation section so i spent some time today writing all of that out.

---------------

For the assembly i documented every step from soldering the headers on the pi zero 2w all the way to closing the shell with m2 screws and nuts. it was actually useful to write it all out because i realized some things i hadnt fully thought through yet like wire management inside the shell.

i also added a "Why I Built This" section to the README explaining how i found the simplyRetroZ5 and decided to build something similar but completely from scratch since i had never done CAD or schematics before.

here is the updated assembly instructions preview:

Assembly Instructions

You can read the full assembly instructions here: [ASSEMBLY.md](https://github.com/Rexaintreal/HermesHandheld/blob/main/ASSEMBLY.md)

---------------

and here is the README with the new motivation section added:

README Preview

---------------

**Total time spent: 30 minutes**

# May 7: Got the Grant and Ordered Parts

So today i got the Forge grant of $40 for HermesHandheld!! i was so happy when i saw this email!!!!

Grant Email

so now i actually had money to buy parts and start building. the plan was always to get the core stuff first since $40 is not enough to buy everything from the BOM at once. i need to be smart about what i buy first so i can actually start testing and logging real hours.

the most important thing to get first is obviously the **Raspberry Pi Zero 2W** since without it literally nothing else can be tested. then i need a **MicroSD card** to flash the OS onto. and since i already have a monitor at home i can skip buying the waveshare display for now and save that $30 for later which is huge.

i also had to figure out the HDMI situation. the Pi Zero 2W uses **Mini HDMI** (not micro hdmi) so i needed a mini hdmi to hdmi cable to connect to my monitor. i just googled it to confirm and yeah its definitely mini hdmi on the zero 2w.

for the smaller stuff like breadboard, buttons, jumper wires and headers i needed those too so i can start wiring up buttons and testing GPIO once the pi arrives.

now for finding the best deals i compared **robocraze** vs **sharvi electronics** for the components and sharvi was significantly cheaper. robocraze was coming out to ₹1,624 for the same stuff while sharvi was ₹1,273 so i went with sharvi. for the Pi Zero 2W itself i found it in stock at **Silverline India** for ₹1,500 + GST.

one thing i caught while building the sharvi cart was that i had a **female** 2x20 header in there at first which would NOT work for soldering onto the Pi Zero 2W. you need the male header for that. swapped it out for the correct **2x20 40Pin Male Double Row Straight Berg Strip** header before ordering. also grabbed x3 of them and x5 slide switches as it was the minimum order limit.

placed the silverline order first:

Silverline Order

then placed the sharvi order:

Sharvi Order

i still have 5.91 dollars left i will return that and ig will get the coins back 

Transactions

total spent was ₹1,770 (silverline) + ₹1,453 (sharvi) = **₹3,223 (~$34)** leaving around $5.90 buffer. 

---------------

after ordering i also updated the **BOM.md** since the links and prices i had before were outdated. swapped robocraze links to sharvi for the stuff i actually bought there, updated unit prices to match what i actually paid, added the correct **2x20 male berg strip header** entry and removed the old generic header pins row. total BOM cost came down from $145 to **$127.81** since sharvi is cheaper than the original sources i had listed.

once the parts arrive the plan is:
- solder the header pins onto the Pi Zero 2W
- flash RetroPie or Batocera to the MicroSD
- boot the Pi on my monitor and verify everything works
- wire all 10 buttons on the breadboard and test GPIO inputs with a python script
- map buttons in RetroPie

that should be a solid few sessions worth of journaling before i even need to think about buying the display, powerboost or battery.

**Total time spent: 30 minutes**

# May 24: Parts Arrived, Life Happened

So both orders finally arrived while i was away but a lot happened in between.

On May 9th my grandfather passed away and we had to travel 400km for the last rites. Hindu funeral rituals are 14 days long so i was completely off my desk with no laptop or anything for almost two weeks. My neighbour received both packages while i was gone which was a relief at least.

The Sharvi Electronics order got delivered on **13/05/2026 at 1:53 PM** and the Silverline order came in earlier on **11th May at 2:56 PM**.

i got back to my desk recently and finally unboxed everything to verify nothing was missing or damaged.

---------------

both packages were sitting there waiting for me lol

---------------
Packages

---------------

the silverline box had the Pi Zero 2W in its official antistatic bag packed inside a cardboard box with crumpled newspaper as padding. it felt good to finally hold it

---------------
Pi Zero 2W

---------------

the sharvi order had everything else the SanDisk 32GB microSD, the mini HDMI to HDMI cable, the breadboard, all the jumper wire packs and the header strips all in blue antistatic bags

---------------
Sharvi Components

---------------

i also checked the packing slip and everything matched the order HDMI cable, slide switches, tactile buttons, M-M M-F F-F jumper wires, breadboard, microSD and the 2x20 male berg strip headers. 26 items total across 9 line items all accounted for

---------------
Packing Slip

---------------

nothing is damaged everything is here so the plan now is to finally get to work. next session i will solder the header pins onto the Pi Zero 2W, flash RetroPie onto the microSD and do the first boot on my monitor to verify everything works before touching any GPIO stuff

---------------

**Total time spent: 20 minutes**

# May 25: First Boot Attempt Everything That Could Go Wrong, Did

So today was the day i was finally going to boot the Pi Zero 2W for the first time. It did not go as planned at all.

---------------

First i laid out everything on the desk the Pi Zero 2W, the SanDisk 32GB microSD, the mini HDMI cable, the header strips, and the mini HDMI to HDMI cable.

---------------

Parts laid out

---------------

The first problem hit immediately. My laptop has no SD card slot so i couldn't flash directly. I tried a USB to SD card adapter but the laptop wasn't detecting it at all. Ok no worries... I have a Raspberry Pi 5 sitting around that i use as a home server. so nnow Plan B: use the Pi 5 to flash the microSD

---------------

But to use the Pi 5 i needed it running first. Since i wanted to flash the Zeros SD card from the Pi 5, i decided to boot the Pi 5 from a USB drive instead so the SD card slot would be free. I opened Raspberry Pi Imager and selected Raspberry Pi OS 64-bit (released April 21 2026, Debian Trixie) which officially supports the Zero 2W.

---------------

OS Selection

---------------

I flashed the OS onto the HP USB drive using Raspberry Pi Imager v2.0.3. Writing went fine hit 35% then completed successfully.

---------------

Writing 35%

---------------

But when i tried booting the Pi 5 from the USB drive it threw a wall of errors. The bootloader was complaining about USB boot requiring high current (5V 5A) and the USB drive was just too slow it kept crashing before completing the boot. I tried again but same result :(

---------------

Boot errors

---------------

I also tried balenaEtcher as an alternative flashing tool but it threw its own error "The writer process ended unexpectedly" so that was a dead end too

---------------

Etcher error

---------------

Okay new plan. I removed the USB drive and booted the Pi 5 normally from its own SD card. Now i could use Raspberry Pi Imager running on the Pi 5 itself to flash the 32GB SanDisk microSD directly. I selected Raspberry Pi Zero 2W as the target device this time.

---------------

Device selection Zero 2W

---------------

The Pi 5 did not detect my sd card but detected the usb drive as a VendorCo ProductCode device. Writing started, got to 48% at 26 MB/s, then completed. Write complete screen confirmed: Device Raspberry Pi 5, OS Raspberry Pi OS 32-bit, Storage VendorCo ProductCode USB Device. Hostname, localisation, and user account all configured.

---------------

Writing 48%

---------------

Write complete

---------------

i also tried balenaEtcher on the Pi 5 with the arm64 image, 6.5GB. it was flashing at 25.30 MB/s and got to 20% with an ETA of 3m25s before i stopped it since Raspberry Pi Imager had already done the job.

---------------

Etcher flashing 20%

---------------

i also tried the Pi 5's built in network installer which was downloading and the writing screen on the monitor showed 

---------------

Downloading installer

---------------

Writing 3% on monitor

---------------

Now i pulled out the microSD, slotted it into the Pi Zero 2W, plugged in the mini HDMI cable to the monitor and connected the microUSB cable from my laptop to power it. This is what it looked like the SD card in, mini HDMI connected, and the blue microUSB going to my laptop for power.

---------------

Pi Zero 2W with cables connected

---------------

Nothing. Black screen. No green LED no boot activity no life at all. I tried with a random charger i had lying around but the amperage was probably wrong and it still didn't boot.

Then i tried putting the microSD into another laptop that had a full size SD card slot using an adapter. Not detected. I tried it in my phone. Also not detected.

---------------

No storage devices found

---------------

At this point i'm pretty sure the SanDisk 32GB microSD is either corrupted or was DOA. It was from the Sharvi order which arrived while i was away for two weeks. Too late for returns. The Pi Zero 2W itself i still haven't been able to confirm is working because i can't power it properly without a proper 5V microUSB charger, and i can't boot it without a working SD card.

Two and a half hours and i hit a wall on both fronts at the same time.

---------------

The Pi 5 itself is fine i confirmed it boots to Raspberry Pi OS desktop (64-bit, March 2026) properly so at least that part works

---------------

Pi 5 booting fine

---------------

Pi Desktop welcome screen

---------------

What i need to unblock this:
- A new microSD card (the 32GB SanDisk appears to be dead)
- A proper 5V microUSB charger so i can actually power the Pi Zero 2W

Until i have both of those i can't confirm whether the Pi Zero 2W itself is working. Everything is on hold.

---------------

**Total time spent: 2.5 hours**

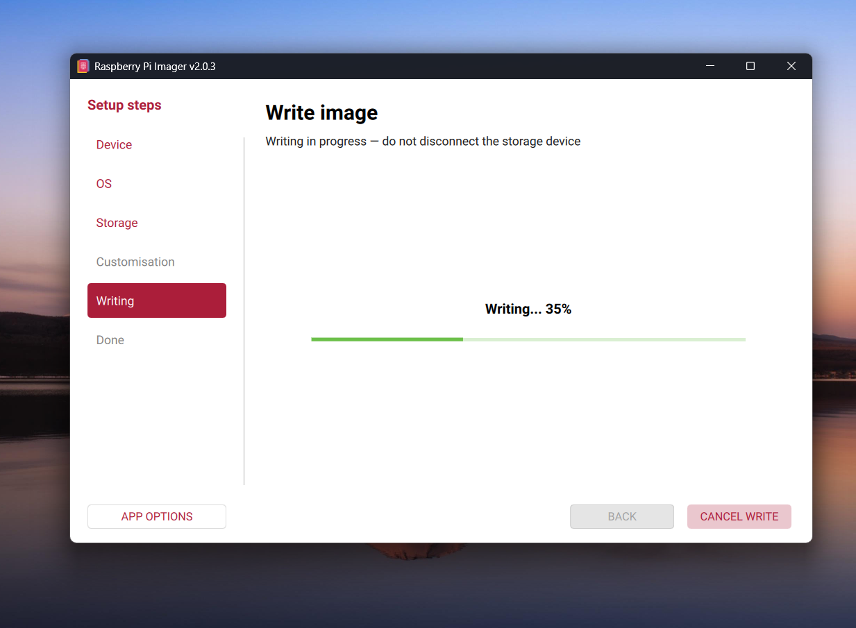
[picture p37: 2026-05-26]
images/Journal10Image3.png

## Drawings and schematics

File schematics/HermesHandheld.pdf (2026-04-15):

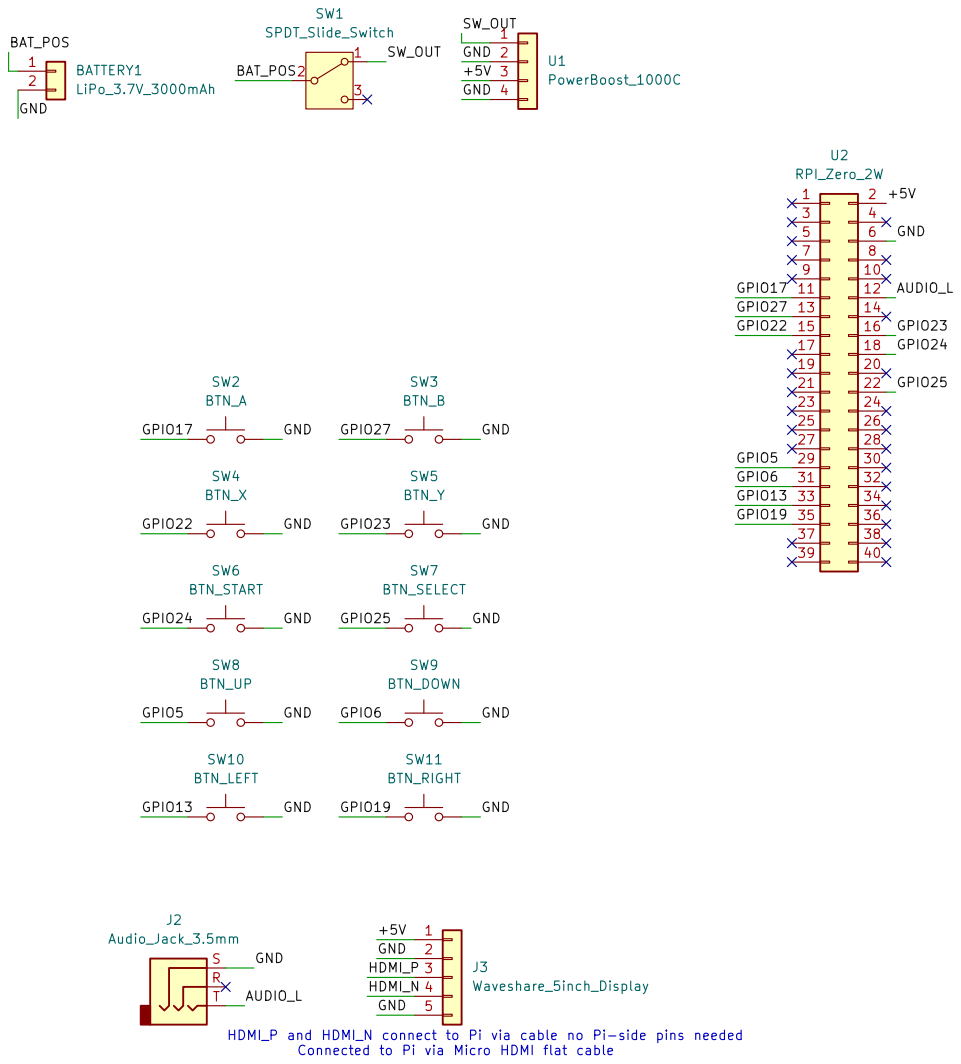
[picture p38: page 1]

Connected to Pi via Micro HDMI flat cable HDMI_P and HDMI_N connect to Pi via cable no Pi-side pins needed

Size: A4 | Rev:
KiCad E.D.A. 10.0.0 | Id: 1/1

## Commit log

2026-04-14 Add BOM with item details and pricing
2026-04-14 Document project details for Hermes handheld console
    Added detailed project notes for the Hermes handheld console, including parts and specifications for core components like the display, battery, audio, and controls.
2026-04-15 Add schematic creation details for April 15
    Documented the process of creating the schematic in KiCad, including details about components used and issues encountered.
2026-04-17 Update JOURNAL.md with design progress details
    Documented progress on the bottom shell, power button, ABXY buttons, and DPad designs, including cutout specifications and adjustments made during the CAD session.
2026-04-17 Fix image filename case in JOURNAL.md
    Corrected the image filename case for Journal4Image7.
2026-04-18 Add files via upload
    with audio jack
    [top_shell_ds.stl]
2026-04-18 Update CAD design and add new image
    Added a 3.5 mm audio jack hole to the CAD design and included an additional image.
2026-04-24 Enhance README with detailed project information
    Expanded the README to provide detailed information about the Hermes handheld gaming console, including features, repo structure, CAD, schematic, bill of materials, and build journal.
2026-04-24 Update JOURNAL.md with assembly details and README
    Documented the assembly process of the handheld device in OnShape, including part placement and color adjustments. Added a link to the final assembly and updated README.md for better project document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
2026-04-25 Add schematic image and update PDF link
    Added an image of the schematic and updated the link to the full PDF.
2026-05-01 Create assembly guide for Hermes handheld console
    Added a comprehensive assembly guide for the Hermes handheld gaming console, detailing tools, parts, soldering instructions, and testing procedures.
2026-05-01 Update JOURNAL.md with assembly instructions and README changes
    Added assembly instructions and motivation section to README.md. Documented the assembly process in detail, including wire management and reasoning behind the project.
2026-05-01 Update link to full assembly instructions in JOURNAL.md
2026-05-01 Update print quantity for abxy_button.stl
2026-05-07 Revise journal entries and BOM updates
    Updated images and corrected header details in the journal. Adjusted BOM prices and entries based on actual purchases.
2026-05-26 Add journal entry for Raspberry Pi Zero 2W boot attempt
    Documented the first boot attempt of the Raspberry Pi Zero 2W, detailing the issues faced with flashing the microSD card and powering the device.
